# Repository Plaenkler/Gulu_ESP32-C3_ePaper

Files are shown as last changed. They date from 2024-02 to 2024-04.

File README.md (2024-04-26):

# Gulu ESP32-C3 ePaper Devboard

<table>
  <tr>
    <td>Gulu ESP32-C3 ePaper Devboard Front</td>
    <td>Gulu ESP32-C3 ePaper Devboard Back</td>
  </tr>
</table>

## About Gulu ESP32-C3 ePaper

Introducing the **Gulu_ESP32-C3_ePaper** Devboard: a cutting-edge development board powered by the ESP32-C3.
This board features a modular power system, equipped with the [Egg_LDO_1000](https://github.com/Plaenkler/Egg_LDO_1000) by default for efficient performance.
Designed to support a wide range of ePaper displays from **WaveShare** and **Good Display** that require the 0.47 Ohm resistor.

## 📖 Specifications

 * MCU: ESP32-C3-WROOM-02-H4
 * Power supply: [Egg_LDO_1000](https://github.com/Plaenkler/Egg_LDO_1000)
 * Connectivity: SPI, UART/USB, 24-pin FPC ePaper connection

## ⚡ Circuit Diagram

gulu_circuit diagram

## Power consumption

The power consumption in deep sleep mode of the ESP32-C3 was measured using the [Power Profiler Kit II](https://www.nordicsemi.com/Products/Development-hardware/Power-Profiler-Kit-2) from Nordic Semiconductor.
The example firmware in this project was used as a benchmark.
A daughter board such as the [Egg_LDO_1000](https://github.com/Plaenkler/Egg_LDO_1000) was not used, and VOUT and GND of the kit were connected directly to the corresponding pads.
During the measurement, a 7.5 inch black and white display ([WFT0583CZ61](https://www.good-display.com/product/396.html)) from [Good Display](https://www.good-display.com) was connected to the FPC port.
The duration of the measurement in this case was one minute after the first cycle of the firmware, which resulted in an average current of **~35μA**.
When the display is not connected, the current is approximately **~10μA** in deep sleep mode.

One_minute_deep_sleep

## Arduino compatibility

During the design phase of the Gulu, a custom set of IO pins was used for the 4-wire SPI connection.
In order for firmware based on the Arduino framework to work on the Gulu, adjustments must be made to the pin definitions.

```cpp
// Default esp32c3>pins_arduino.h
static const uint8_t SS    = 7;
static const uint8_t MOSI  = 6;
static const uint8_t MISO  = 5;
static const uint8_t SCK   = 4;

// Modified esp32c3>pins_arduino.h
static const uint8_t SS    = 7; // EPD_DC
static const uint8_t MOSI  = 4; // EPD_DIN
static const uint8_t MISO  = 6; // EPD_CS
static const uint8_t SCK   = 5; // EPD_SCK
```

## Firmware example

### Display Definition and Image

This section contains a header file with a definition for the display and a sample image.
The display is initialized with the required pins specified for the GxEPD2 library.
Additionally, a sample image is defined as an array of byte data stored in PROGMEM (program memory) of the microcontroller.

```cpp
#ifndef _750_T7_H_
#define _750_T7_H_

#include <GxEPD2_BW.h>

GxEPD2_BW<GxEPD2_750_T7, GxEPD2_750_T7::HEIGHT> display(
  GxEPD2_750_T7(6, 7, 10, 3)
);

const unsigned char image[] PROGMEM = {
    0x55, 0x55, 0x55, 0x6d, 0xb6, 0xdb, 0x6d, 0xb5, 0x6a, 0xbf, 0xf5, 0x22, ...
```

### Main Program

The first section initializes the necessary components for the firmware.
Firstly, the onboard LED (connected to pin 0) is configured as an output.
Then, the display initialization is called.

```cpp
#include "750_T7.h"

void setup() {
  pinMode(0, OUTPUT);
  display.init();
}
```

In the main part of the program, the sample picture is displayed on the screen, after which the screen is switched to hibernation mode.
Subsequently, the onboard LED is turned on for one second and then turned off.
After that, a timer wakeup for the deep sleep mode is enabled, and the microcontroller is put into deep sleep.

```cpp
void loop() {
  display.drawImage(image, 0, 0, 800, 480);
  display.hibernate();
  digitalWrite(0, 1);
  delay(1e3);
  digitalWrite(0, 0);
  esp_sleep_enable_timer_wakeup(1e7);
  esp_deep_sleep_start();
}
```

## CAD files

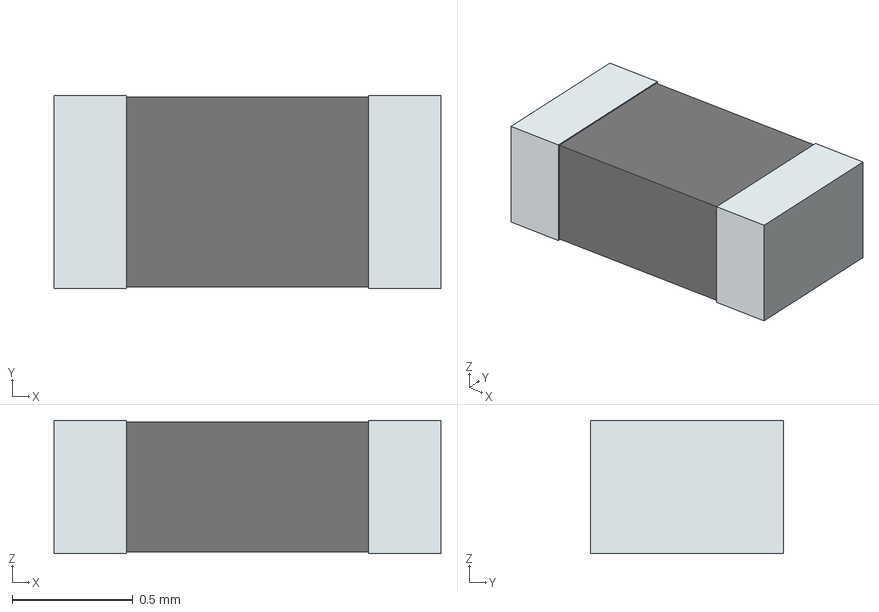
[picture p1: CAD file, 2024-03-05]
Gulu_ESP32-C3_ePaper_3D/ESR03EZPF1002.stp
1.60 x 0.8 x 0.55 mm
term1
term2

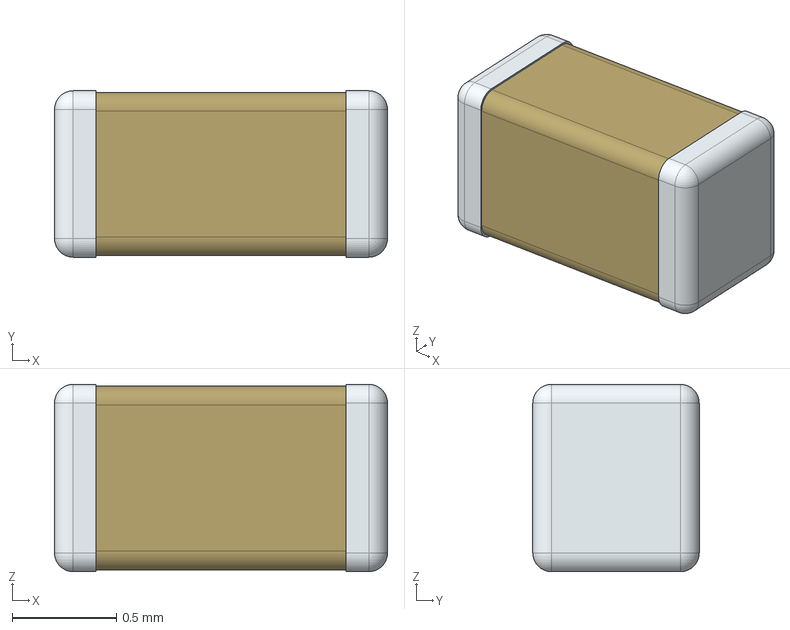
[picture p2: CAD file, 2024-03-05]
Gulu_ESP32-C3_ePaper_3D/CGA3E1X7R1V105K080AC.stp
1.60 x 0.8 x 0.9 mm

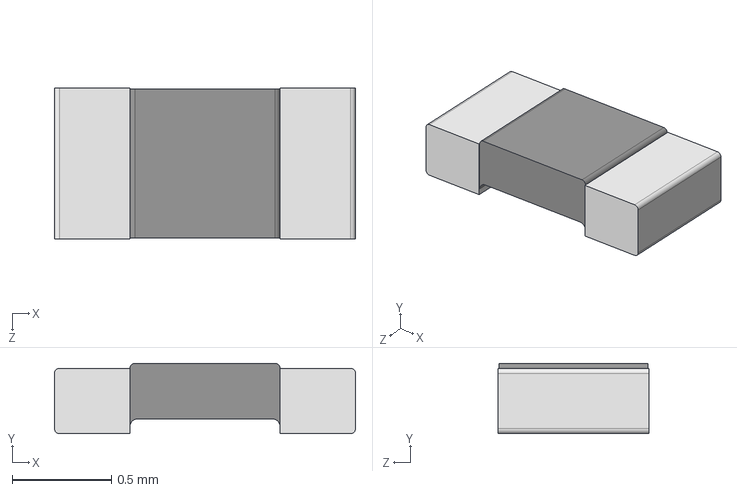
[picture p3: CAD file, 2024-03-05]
Gulu_ESP32-C3_ePaper_3D/RCWE0603R470FKEA.stp
1.52 x 0.355 x 0.76 mm

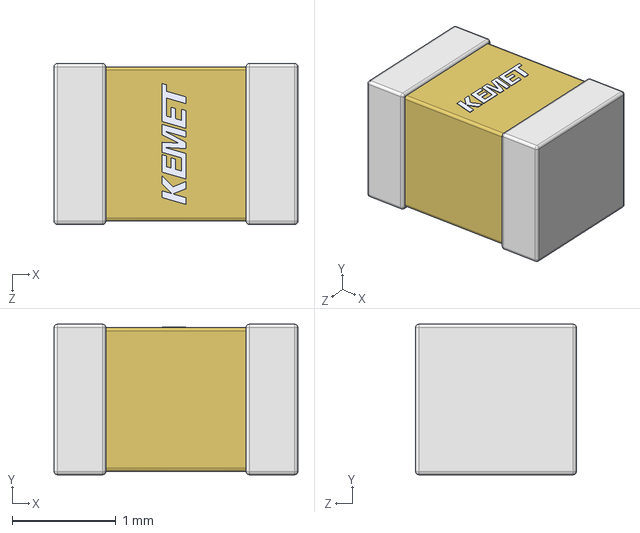
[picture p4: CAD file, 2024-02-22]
Gulu_ESP32-C3_ePaper_3D/C0805X105K5RACAUTO.stp
2.35 x 1.45 x 1.55 mm

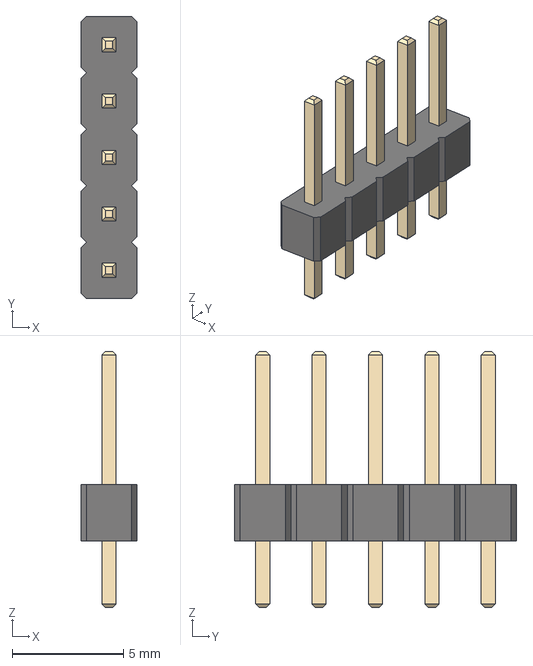
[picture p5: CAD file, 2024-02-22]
Gulu_ESP32-C3_ePaper_3D/PinHeader_1x05_P2.54mm_Vertical.step
2.54 x 12.7 x 11.5 mm

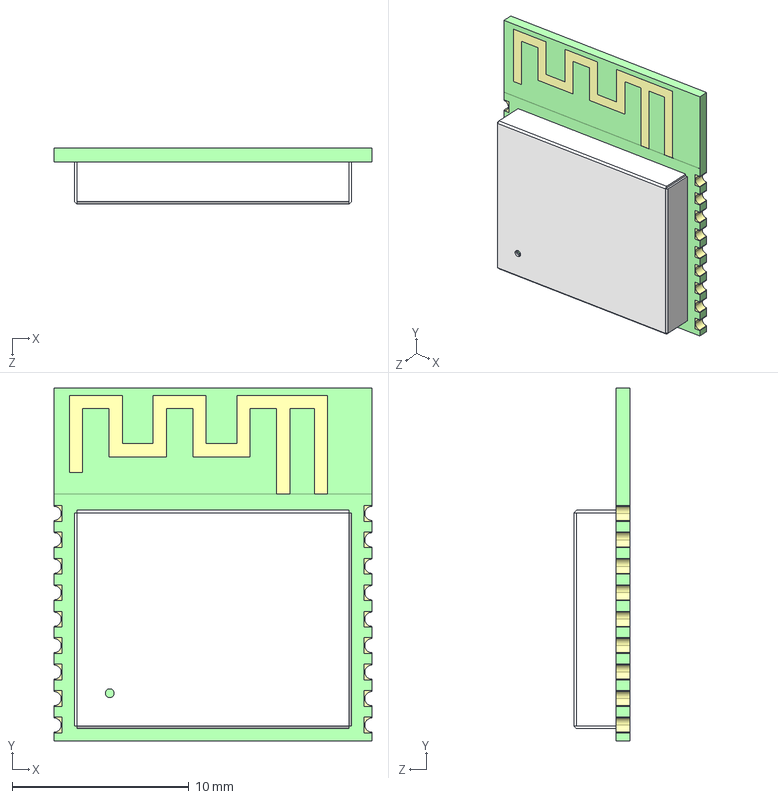
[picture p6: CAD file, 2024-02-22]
Gulu_ESP32-C3_ePaper_3D/ESP32-C3-WROOM-02-H4.stp
18.0 x 20.0 x 3.20 mm

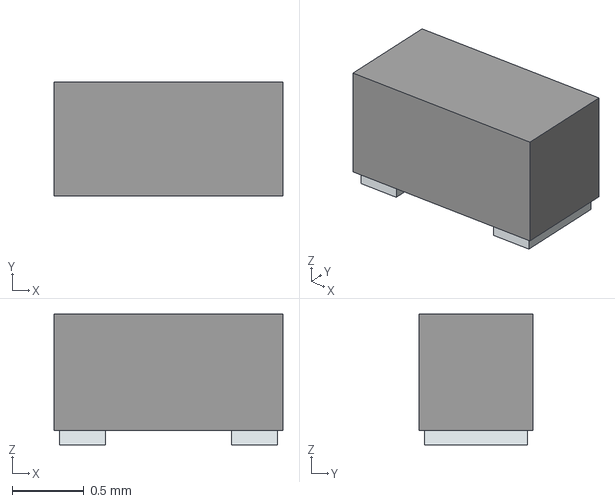
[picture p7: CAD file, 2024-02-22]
Gulu_ESP32-C3_ePaper_3D/598-2000-107F.stp
1.60 x 0.8 x 0.913 mm
Pins

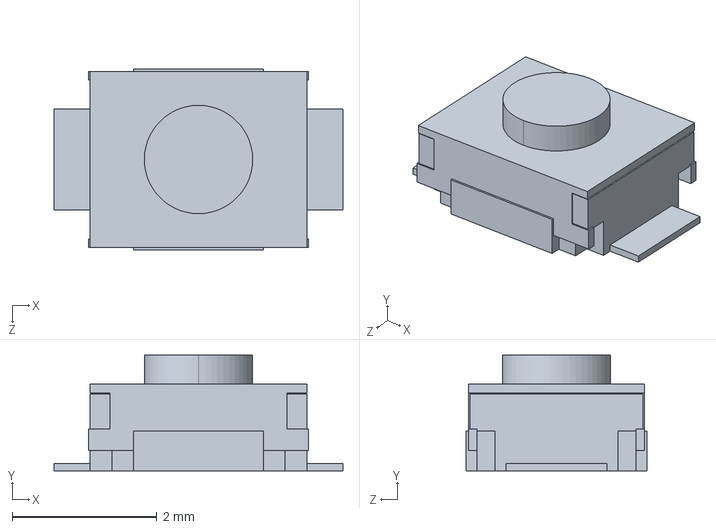
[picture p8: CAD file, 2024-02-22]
Gulu_ESP32-C3_ePaper_3D/B3U-1000P.stp
4.00 x 1.60 x 2.50 mm

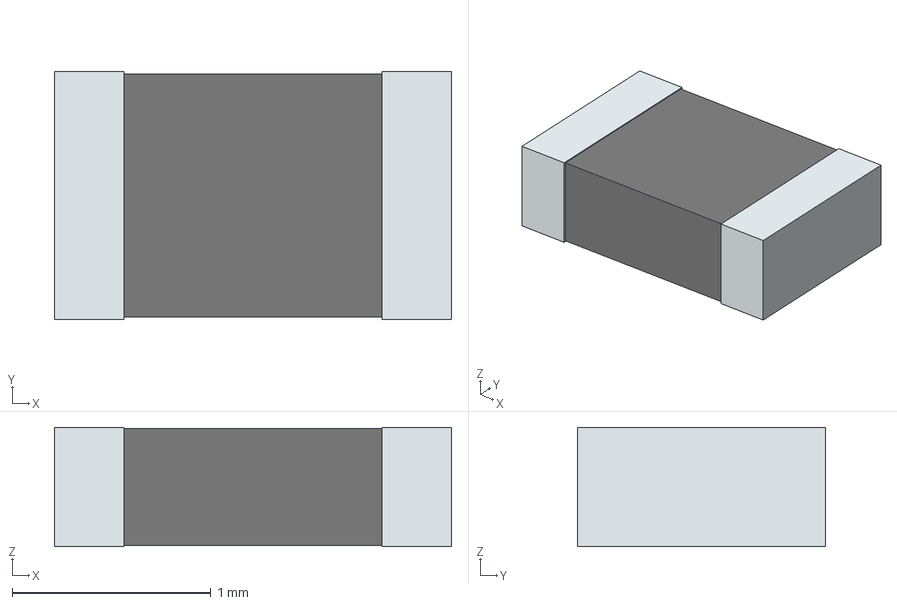
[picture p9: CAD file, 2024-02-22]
Gulu_ESP32-C3_ePaper_3D/AC0805FR-7W60R4L.stp
2.00 x 1.25 x 0.6 mm
term1
term2

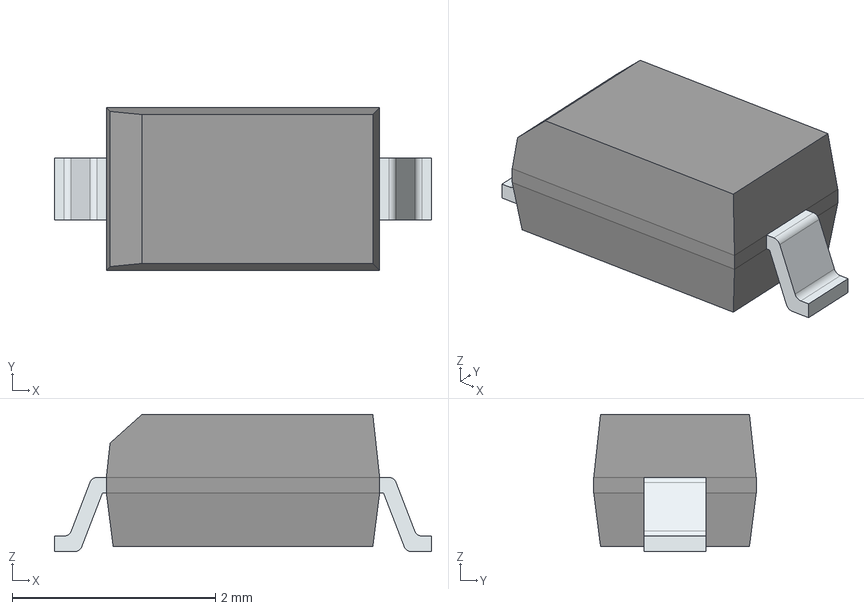
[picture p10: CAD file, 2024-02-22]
Gulu_ESP32-C3_ePaper_3D/MBR0530T1G.stp
3.71 x 1.60 x 1.35 mm
FilletPinL
FilletPinR

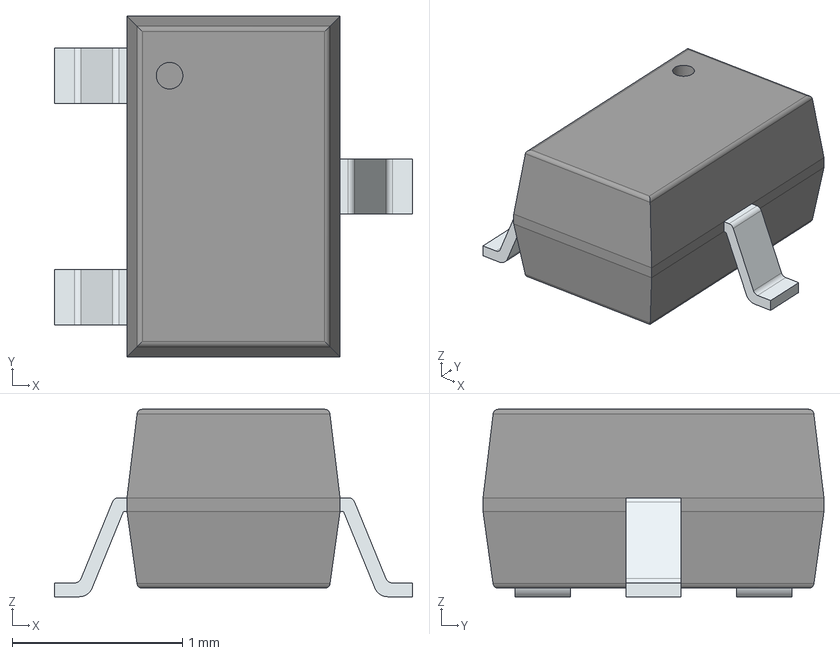
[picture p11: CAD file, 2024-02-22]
Gulu_ESP32-C3_ePaper_3D/Si1308EDL-T1-GE3.stp
2.10 x 2.00 x 1.10 mm
PinsArrayL
FilletPinR

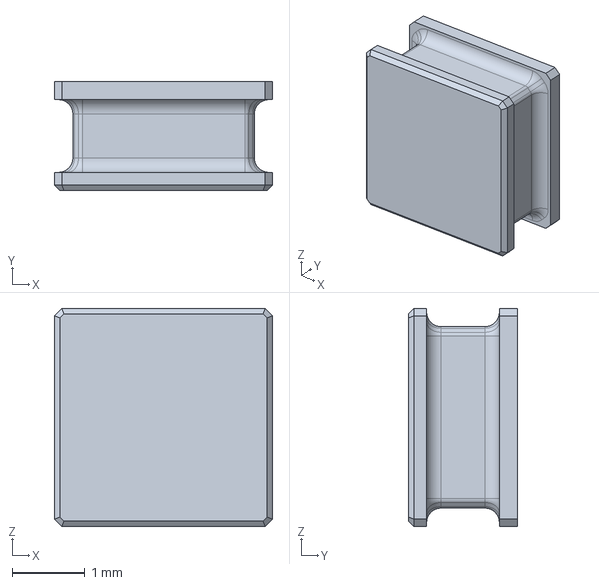
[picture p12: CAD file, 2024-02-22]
Gulu_ESP32-C3_ePaper_3D/SRN3015-100M.stp
3.00 x 1.50 x 3.00 mm

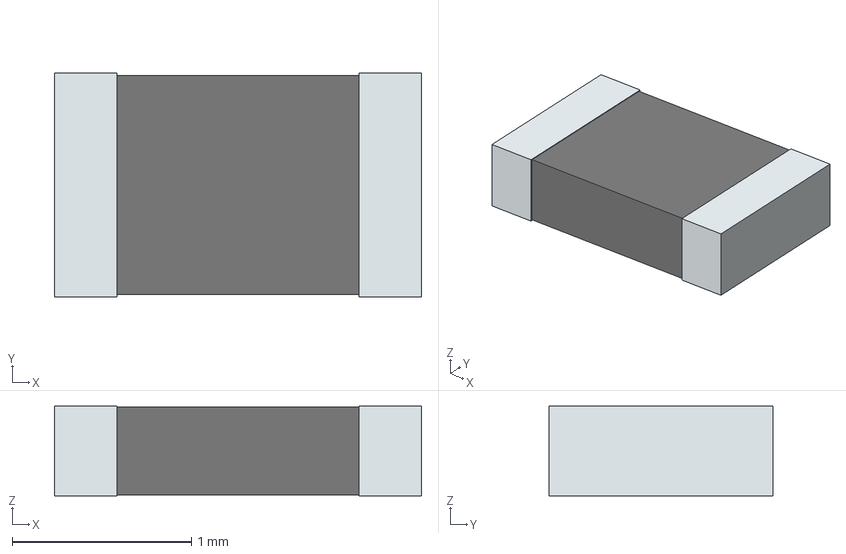
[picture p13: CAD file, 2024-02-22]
Gulu_ESP32-C3_ePaper_3D/RCWL0805R470JNEA.stp
2.05 x 1.25 x 0.5 mm
term1
term2

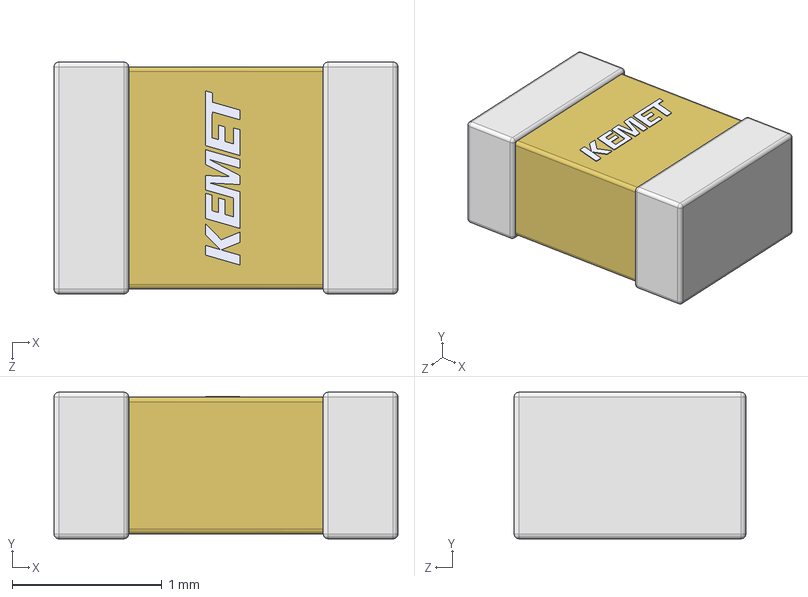
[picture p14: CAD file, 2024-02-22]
Gulu_ESP32-C3_ePaper_3D/C0805X104J5RACTU.stp
2.30 x 0.98 x 1.55 mm

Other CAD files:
Gulu_ESP32-C3_ePaper_3D/52435-2471.stp

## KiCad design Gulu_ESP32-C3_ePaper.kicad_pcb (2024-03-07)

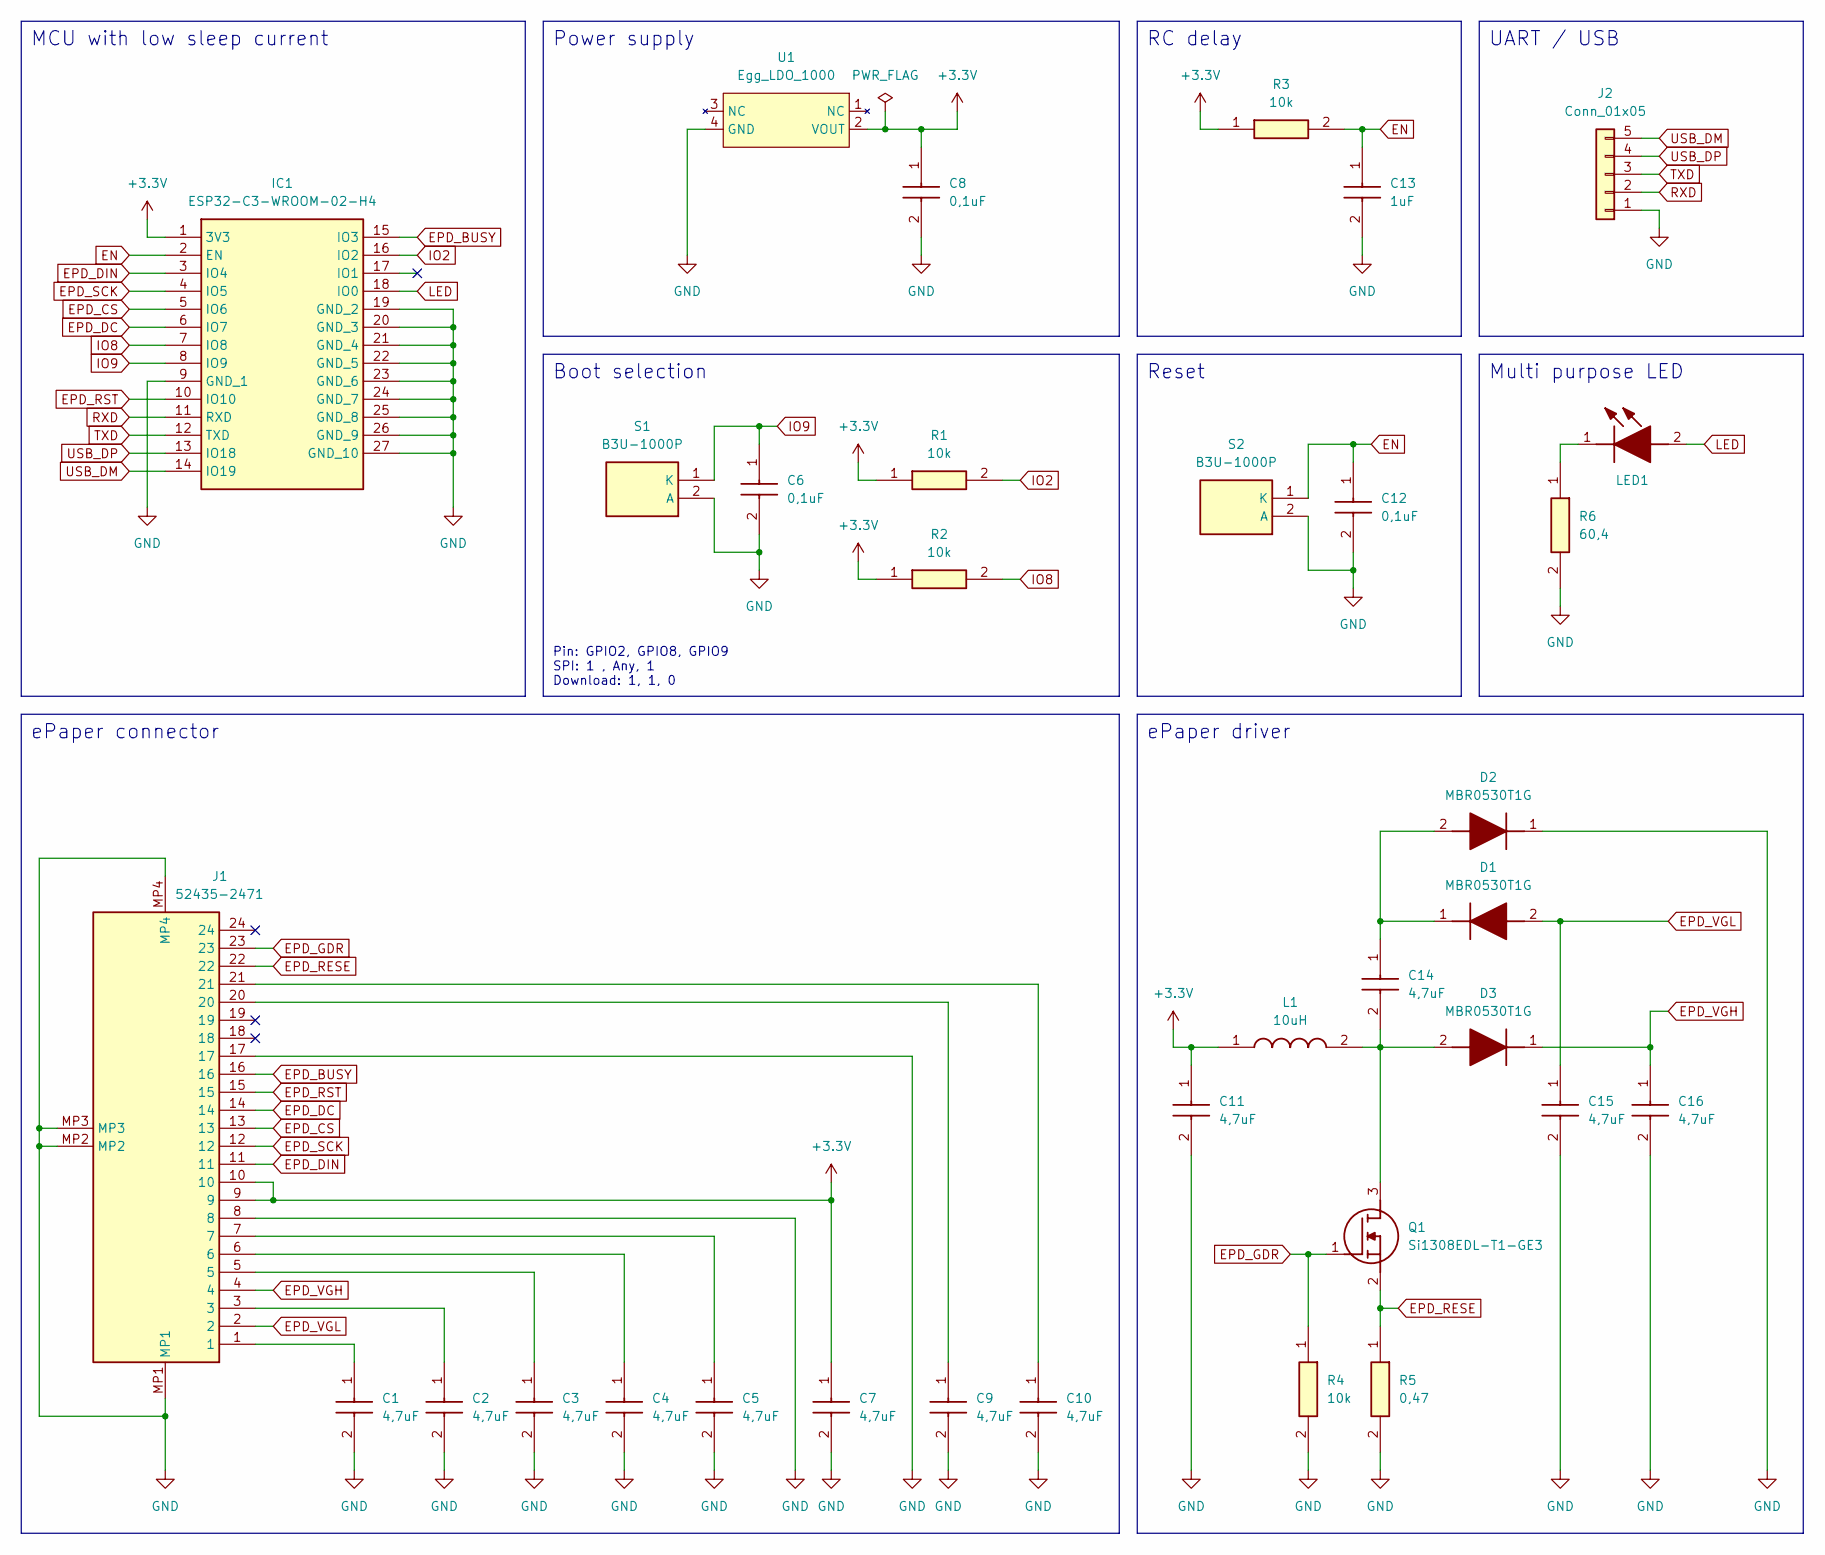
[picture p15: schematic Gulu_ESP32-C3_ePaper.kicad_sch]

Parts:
C1, C2, C3, C4, C5, C7, C9, C10, C11, C14, C15, C16: 4,7uF; CAPC1608X90N; Mouser Part Number 81-GRM188R6YA475KE5D
C6, C8, C12: 0,1uF; CAPC1608X90N; Mouser Part Number 581-KAM15AR71H104KM
C13: 1uF; CAPC1608X90N; Mouser Part Number 810-CGA3E1X7R1V105KC
D1, D2, D3: MBR0530T1G; SOD3716X135N; Mouser Part Number 863-MBR0530T1G
IC1: ESP32-C3-WROOM-02-H4; ESP32C3WROOM02H4; Mouser Part Number 356-ESP32C3WROOM02H4
J1: 52435-2471; 524352471; Mouser Part Number 538-52435-2471
J2: Conn_01x05; PinHeader_1x05_P2.54mm_Vertical
L1: 10uH; SRN3015; Mouser Part Number 652-SRN3015-100M
LED1: 598-2000-107F; 5982000107F; Manufacturer_Part_Number 598-2000-107F
Q1: Si1308EDL-T1-GE3; SOT65P210X110-3N; Mouser Part Number 78-SI1308EDL-T1-GE3
R1, R2, R3, R4: 10k; RESC1608X55N; Mouser Part Number 755-ESR03EZPF1002
R5: 0,47; RESC1608X60N; Mouser Part Number 71-RCWE0603R470FKEA
R6: 60,4; RESC2012X60N; Manufacturer_Part_Number AC0805FR-7W60R4L
S1, S2: B3U-1000P; Mouser Part Number 653-B3U-1000P
U1: Egg_LDO_1000

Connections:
+3.3V: C7.1, C8.1, C11.1, IC1.1 (3V3), J1.9, J1.10, L1.1, R1.1, R2.1, R3.1, U1.2 (VOUT)
EN: C12.1, C13.1, IC1.2 (EN), R3.2, S2.1 (K)
EPD_BUSY: IC1.15 (IO3), J1.16
EPD_CS: IC1.5 (IO6), J1.13
EPD_DC: IC1.6 (IO7), J1.14
EPD_DIN: IC1.3 (IO4), J1.11
EPD_GDR: J1.23, Q1.1 (G), R4.1
EPD_RESE: J1.22, Q1.2 (S), R5.1
EPD_RST: IC1.10 (IO10), J1.15
EPD_SCK: IC1.4 (IO5), J1.12
EPD_VGH: C16.1, D3.1 (K), J1.4
EPD_VGL: C15.1, D1.2 (A), J1.2
GND: C1.2, C2.2, C3.2, C4.2, C5.2, C6.2, C7.2, C8.2, C9.2, C10.2, C11.2, C12.2, C13.2, C15.2, C16.2, D2.1 (K), IC1.9 (GND_1), IC1.19 (GND_2), IC1.20 (GND_3), IC1.21 (GND_4), IC1.22 (GND_5), IC1.23 (GND_6), IC1.24 (GND_7), IC1.25 (GND_8), IC1.26 (GND_9), IC1.27 (GND_10), J1.8, J1.17, J1.MP1, J1.MP2, J1.MP3, J1.MP4, J2.1, R4.2, R5.2, R6.2, S1.2 (A), S2.2 (A), U1.4 (GND)
IO2: IC1.16 (IO2), R1.2
IO8: IC1.7 (IO8), R2.2
IO9: C6.1, IC1.8 (IO9), S1.1 (K)
LED: IC1.18 (IO0), LED1.2 (A)
unnamed: C1.1, J1.1
unnamed: C2.1, J1.3
unnamed: C3.1, J1.5
unnamed: C4.1, J1.6
unnamed: C5.1, J1.7
unnamed: C9.1, J1.20
unnamed: C10.1, J1.21
unnamed: C14.1, D1.1 (K), D2.2 (A)
unnamed: C14.2, D3.2 (A), L1.2, Q1.3 (D)
unnamed: LED1.1 (K), R6.1
RXD: IC1.11 (RXD), J2.2
TXD: IC1.12 (TXD), J2.3
USB_DM: IC1.14 (IO19), J2.5
USB_DP: IC1.13 (IO18), J2.4

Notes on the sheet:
ePaper connector
Multi purpose LED
MCU with low sleep current
RC delay
Reset
UART / USB
Boot selection
Pin: GPIO2, GPIO8, GPIO9 SPI: 1 , Any, 1 Download: 1, 1, 0
ePaper driver
Power supply

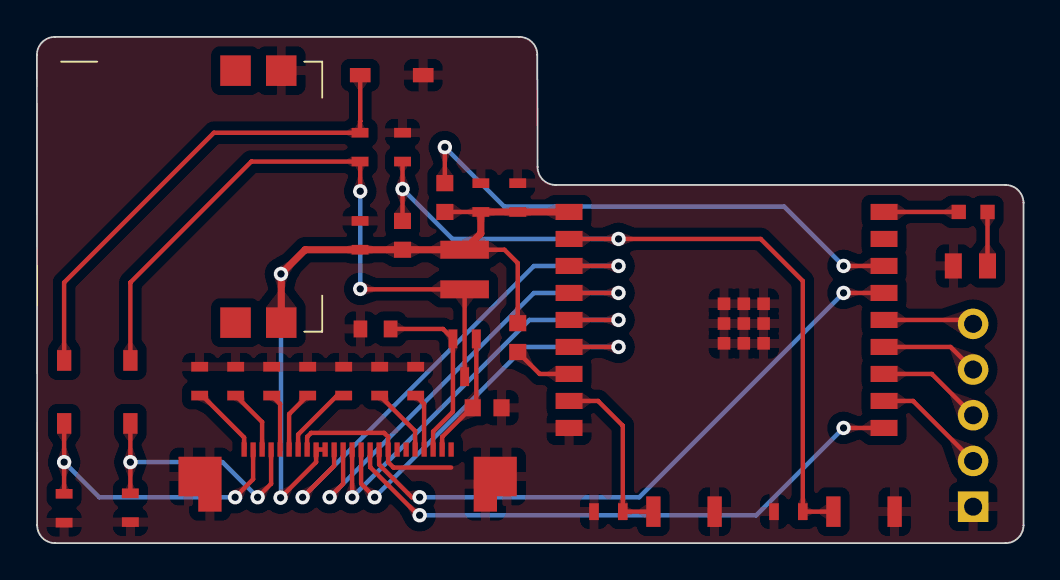
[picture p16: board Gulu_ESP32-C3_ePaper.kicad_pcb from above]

Board: 2 copper layers, 54.8 x 28.1 mm, 34 parts (0 on the bottom side), 31 nets.

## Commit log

2024-01-28 [ADD] Current state
    [Gulu_ESP32-C3_ePaper.kicad_pcb, Gulu_ESP32-C3_ePaper.kicad_sch]
2024-02-02 [UPD] 0805 components
    [Gulu_ESP32-C3_ePaper.kicad_pcb, Gulu_ESP32-C3_ePaper.kicad_sch]
2024-02-06 [UPD] Small 68uH coil
    [Gulu_ESP32-C3_ePaper.kicad_sch]
2024-02-08 [UPD] Reorganized IO pins
    [Gulu_ESP32-C3_ePaper.kicad_sch]
2024-02-19 [UPD] Revised circuit diagram
    - USB header added
    - Power supply replaced by Egg_LDO_1000
    - DIN and SCK pin assignment corrected
    [Gulu_ESP32-C3_ePaper.kicad_sch]
2024-02-22 [UPD] Completely new design
    [Gulu_ESP32-C3_ePaper.kicad_pcb]
2024-02-22 [UPD] Added LED and relocated pins
    [Gulu_ESP32-C3_ePaper.kicad_sch]
2024-02-22 [ADD] 3D models
    [52435-2471.stp, 598-2000-107F.stp, AC0805FR-7W60R4L.stp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]
2024-02-22 [ADD] Interactive BOM
2024-02-23 [REM] Superfluous button
    [Gulu_ESP32-C3_ePaper.kicad_pcb, Gulu_ESP32-C3_ePaper.kicad_sch]
2024-02-23 [UPD] BOM -> 1.1.0
2024-03-05 [UPD] Replaced components
    0805 -> 0603
    [Gulu_ESP32-C3_ePaper.kicad_pcb, Gulu_ESP32-C3_ePaper.kicad_sch]
2024-03-05 [ADD] New 3D models
    [CGA3E1X7R1V105K080AC.stp, ESR03EZPF1002.stp, RCWE0603R470FKEA.stp]
2024-03-05 [UPD] Version & interactive BOM
    [Gulu_ESP32-C3_ePaper.kicad_pcb, Gulu_ESP32-C3_ePaper.kicad_sch]
2024-03-05 [ADD] Alternative tag mpn
    Export alternative tag in BOM
    [Gulu_ESP32-C3_ePaper.kicad_pcb, Gulu_ESP32-C3_ePaper.kicad_sch]
2024-03-06 [FIX] References & teardrops
    [Gulu_ESP32-C3_ePaper.kicad_pcb, Gulu_ESP32-C3_ePaper.kicad_sch]
2024-04-05 [UPD] README.md
    Describe power consumption in deep sleep mode

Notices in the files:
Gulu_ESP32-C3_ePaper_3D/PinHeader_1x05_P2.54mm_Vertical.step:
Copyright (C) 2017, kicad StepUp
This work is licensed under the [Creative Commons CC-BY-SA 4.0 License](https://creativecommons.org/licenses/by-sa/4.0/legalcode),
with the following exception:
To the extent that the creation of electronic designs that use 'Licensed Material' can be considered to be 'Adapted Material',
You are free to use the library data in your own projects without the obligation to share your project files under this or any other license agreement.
